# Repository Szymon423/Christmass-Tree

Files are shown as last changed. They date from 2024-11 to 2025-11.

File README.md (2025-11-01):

<div align="center">

# Christmass Tree

</div>

This project is about creating chritmass tree made of PCB with bunch of LEDs. There is not much functionality. I just want it to look pretty.

If You have spare Arduino Uno - You can have Your own little christmass tree.

<p align="center">
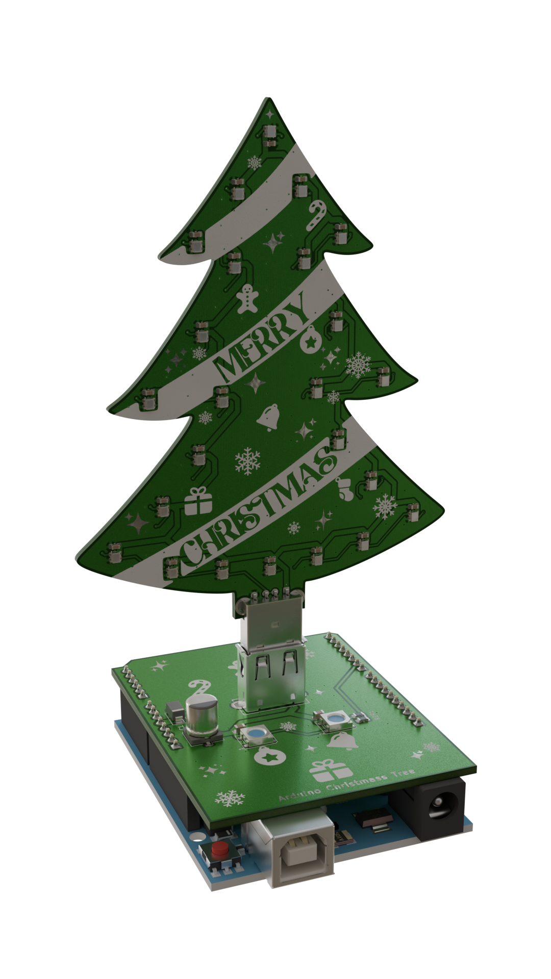
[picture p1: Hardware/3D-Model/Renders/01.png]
opis obrazka
    
</p>

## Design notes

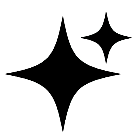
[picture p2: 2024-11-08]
Hardware/KiCad/Assets/star1.png

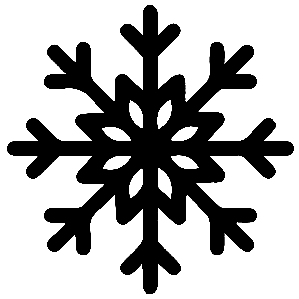
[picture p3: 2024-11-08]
Hardware/KiCad/Assets/snowflake1.png

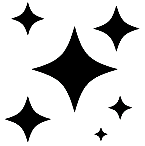
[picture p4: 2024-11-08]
Hardware/KiCad/Assets/star3.png

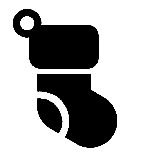
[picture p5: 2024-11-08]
Hardware/KiCad/Assets/sock.png

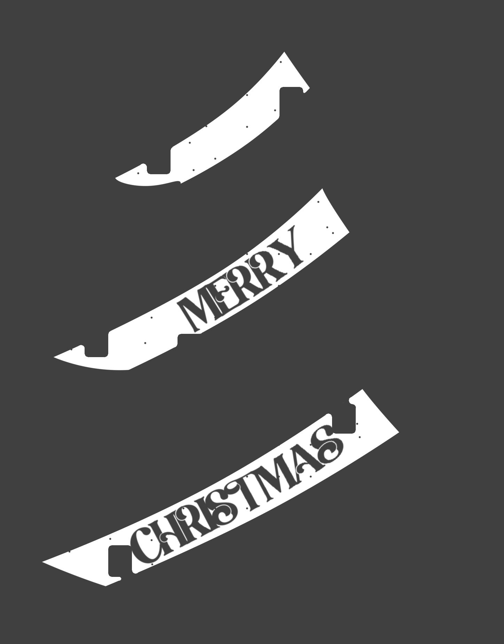
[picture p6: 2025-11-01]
Hardware/KiCad/Assets/Ribbons.png

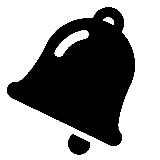
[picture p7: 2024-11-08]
Hardware/KiCad/Assets/bell.png

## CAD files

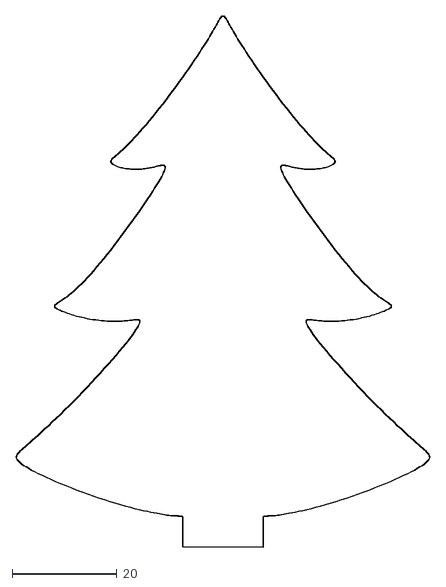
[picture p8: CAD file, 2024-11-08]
Hardware/KiCad/Assets/outline.dxf
78.8 x 101.2

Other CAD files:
Hardware/KiCad/Assets/outline.blend

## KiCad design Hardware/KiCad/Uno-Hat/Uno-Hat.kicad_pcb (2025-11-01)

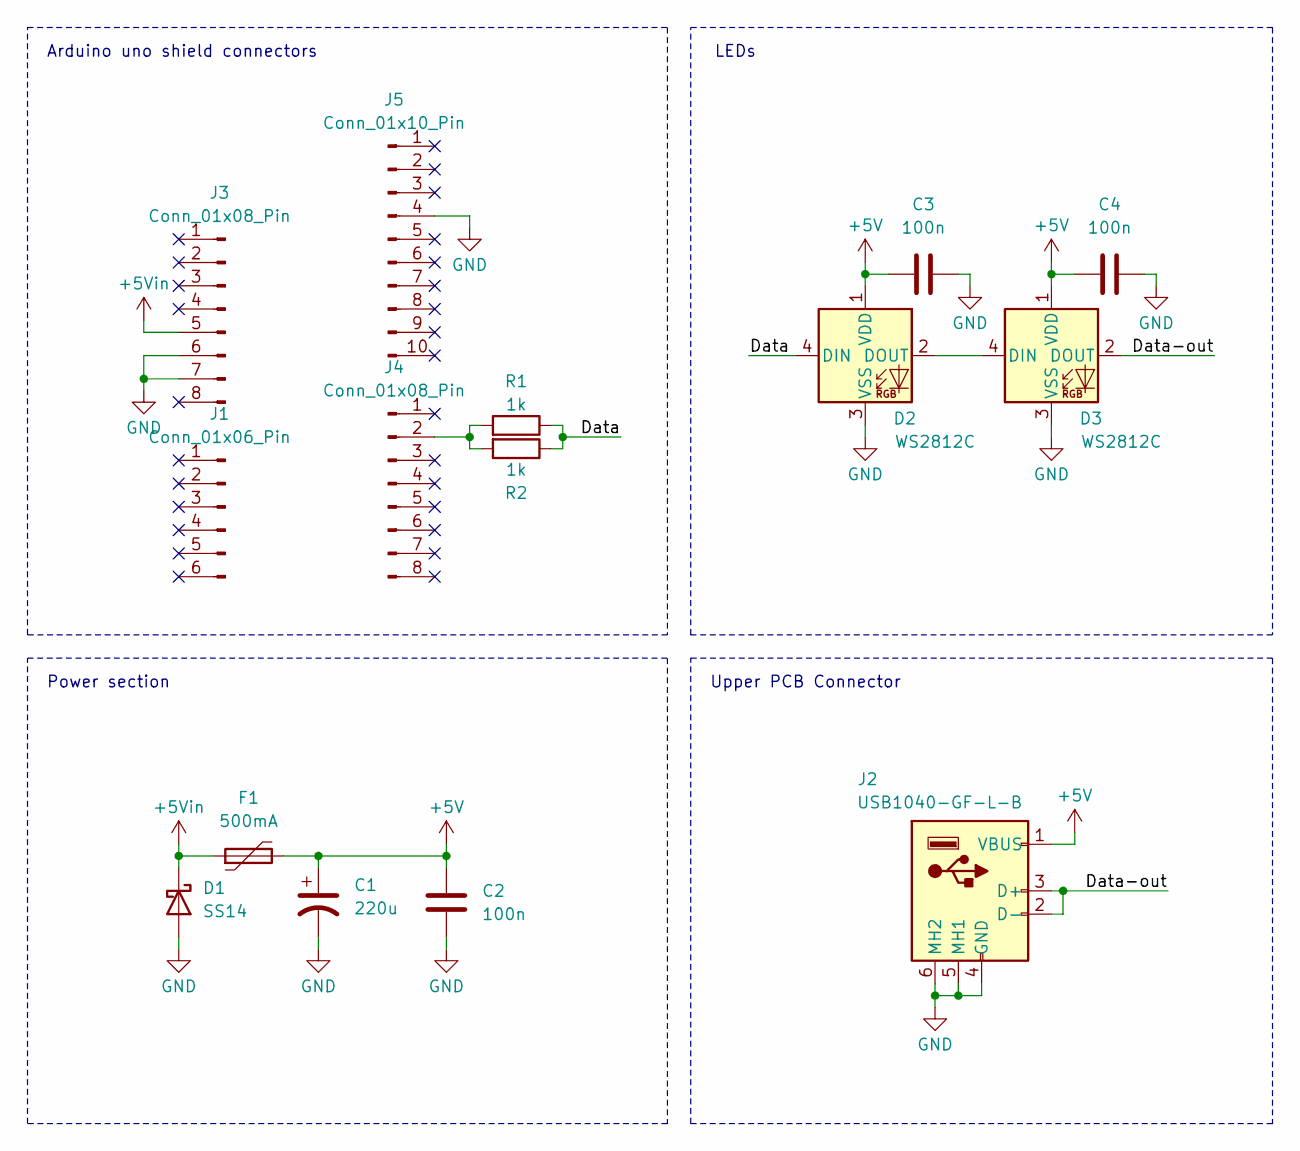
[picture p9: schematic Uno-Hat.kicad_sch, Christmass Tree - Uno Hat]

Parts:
C1: 220u; CP_Elec_6.3x7.7
C2, C3, C4: 100n; C_0805_2012Metric
D1: SS14; D_SMA
D2, D3: WS2812C; LED_WS2812B_PLCC4_5.0x5.0mm_P3.2mm
F1: 500mA; Fuse_1206_3216Metric
J1: Conn_01x06_Pin; PinHeader_1x06_P2.54mm_Vertical
J2: USB1040-GF-L-B; USB1040-GF-L-B-4; Manufacturer_Part_Number USB1040-GF-L-B
J3, J4: Conn_01x08_Pin; PinHeader_1x08_P2.54mm_Vertical
J5: Conn_01x10_Pin; PinHeader_1x10_P2.54mm_Vertical
R1, R2: 1k; R_0805_2012Metric

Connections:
+5V: C1.1, C2.1, C3.1, C4.1, D2.1 (VDD), D3.1 (VDD), F1.2, J2.1 (VBUS)
+5Vin: D1.1 (K), F1.1, J3.5
/Data: D2.4 (DIN), R1.1, R2.1
/Data-out: D3.2 (DOUT), J2.2 (D-), J2.3 (D+)
GND: C1.2, C2.2, C3.2, C4.2, D1.2 (A), D2.3 (VSS), D3.3 (VSS), J2.4 (GND), J2.5 (MH1), J2.6 (MH2), J3.6, J3.7, J5.4
unnamed: D2.2 (DOUT), D3.4 (DIN)
unnamed: J4.2, R1.2, R2.2

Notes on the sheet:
Power section
Arduino uno shield connectors
LEDs
Upper PCB Connector

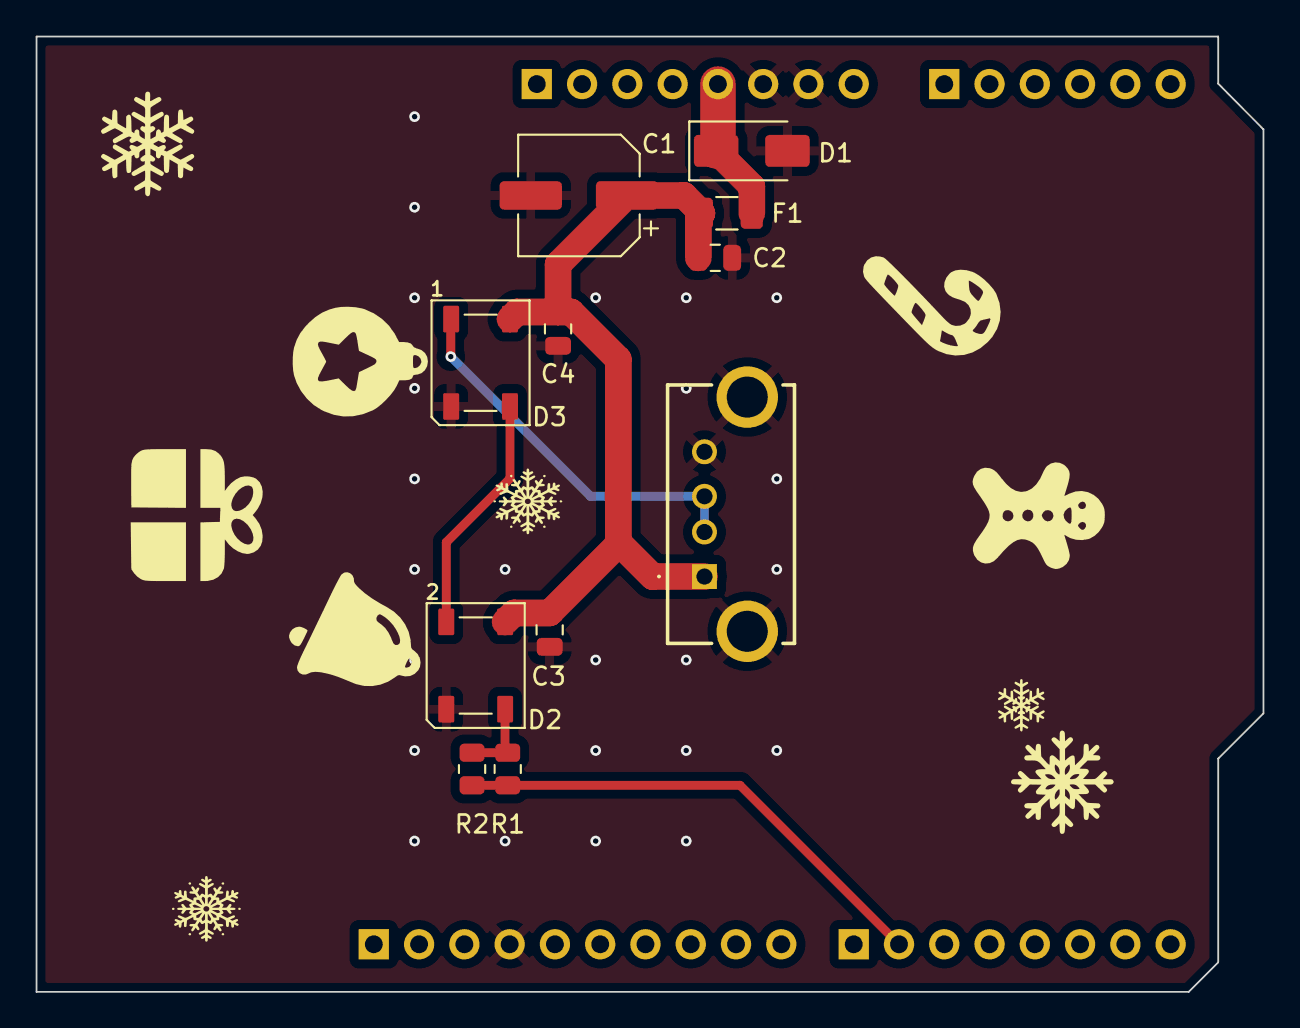
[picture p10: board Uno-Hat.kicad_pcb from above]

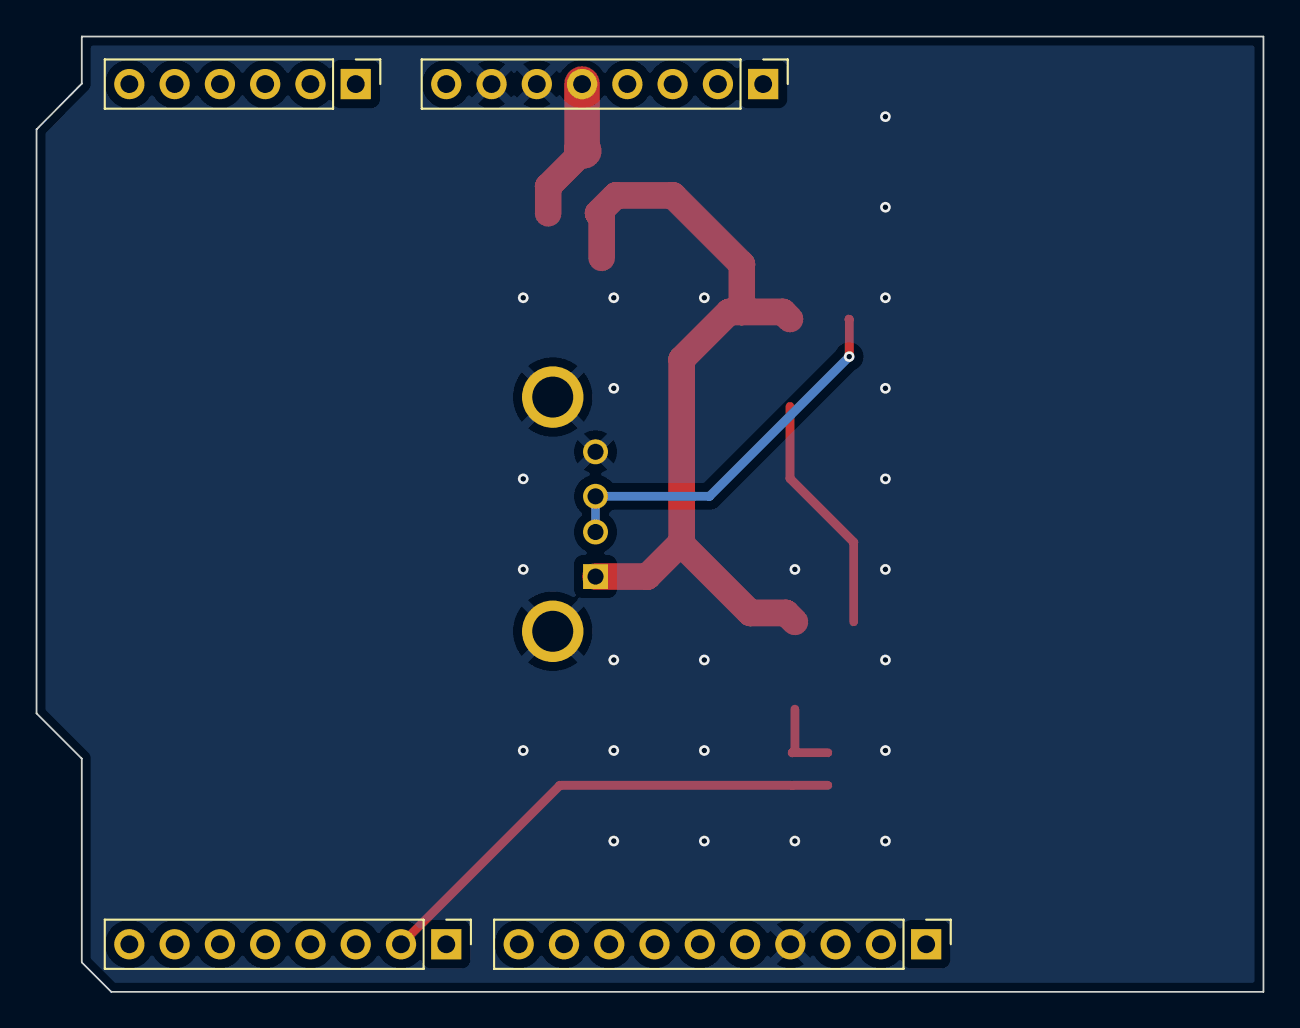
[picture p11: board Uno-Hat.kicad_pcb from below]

Board: 2 copper layers, 68.8 x 53.6 mm, 15 parts (4 on the bottom side), 7 nets.

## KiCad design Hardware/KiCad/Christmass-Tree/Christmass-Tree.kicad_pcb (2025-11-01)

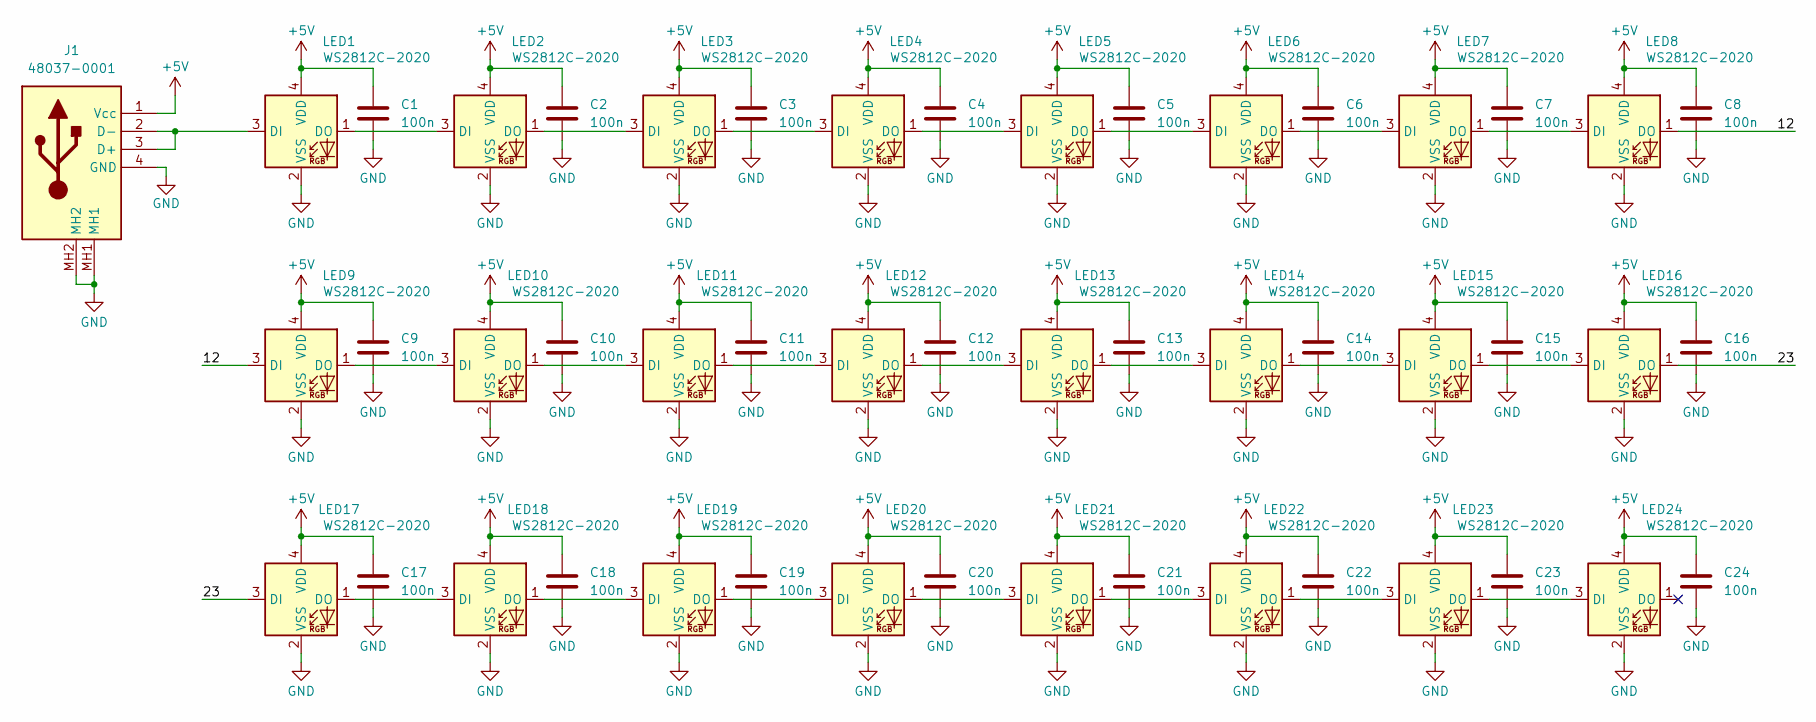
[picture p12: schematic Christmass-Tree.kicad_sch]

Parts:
C1, C2, C3, C4, C5, C6, C7, C8, C9, C10, C11, C12, C13, C14, C15, C16, C17, C18, C19, C20, C21, C22, C23, C24: 100n; C_0603_1608Metric
J1: 48037-0001; 480370001; Manufacturer_Part_Number 48037-0001
LED1, LED2, LED3, LED4, LED5, LED6, LED7, LED8, LED9, LED10, LED11, LED12, LED13, LED14, LED15, LED16, LED17, LED18, LED19, LED20, LED21, LED22, LED23, LED24: WS2812C-2020; WS2812C2020; Manufacturer_Part_Number WS2812C-2020

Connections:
+5V: C1.1, C2.1, C3.1, C4.1, C5.1, C6.1, C7.1, C8.1, C9.1, C10.1, C11.1, C12.1, C13.1, C14.1, C15.1, C16.1, C17.1, C18.1, C19.1, C20.1, C21.1, C22.1, C23.1, C24.1, J1.1 (Vcc), LED1.4 (VDD), LED2.4 (VDD), LED3.4 (VDD), LED4.4 (VDD), LED5.4 (VDD), LED6.4 (VDD), LED7.4 (VDD), LED8.4 (VDD), LED9.4 (VDD), LED10.4 (VDD), LED11.4 (VDD), LED12.4 (VDD), LED13.4 (VDD), LED14.4 (VDD), LED15.4 (VDD), LED16.4 (VDD), LED17.4 (VDD), LED18.4 (VDD), LED19.4 (VDD), LED20.4 (VDD), LED21.4 (VDD), LED22.4 (VDD), LED23.4 (VDD), LED24.4 (VDD)
/12: LED8.1 (DO), LED9.3 (DI)
/23: LED16.1 (DO), LED17.3 (DI)
GND: C1.2, C2.2, C3.2, C4.2, C5.2, C6.2, C7.2, C8.2, C9.2, C10.2, C11.2, C12.2, C13.2, C14.2, C15.2, C16.2, C17.2, C18.2, C19.2, C20.2, C21.2, C22.2, C23.2, C24.2, J1.4 (GND), J1.MH1, J1.MH2, LED1.2 (VSS), LED2.2 (VSS), LED3.2 (VSS), LED4.2 (VSS), LED5.2 (VSS), LED6.2 (VSS), LED7.2 (VSS), LED8.2 (VSS), LED9.2 (VSS), LED10.2 (VSS), LED11.2 (VSS), LED12.2 (VSS), LED13.2 (VSS), LED14.2 (VSS), LED15.2 (VSS), LED16.2 (VSS), LED17.2 (VSS), LED18.2 (VSS), LED19.2 (VSS), LED20.2 (VSS), LED21.2 (VSS), LED22.2 (VSS), LED23.2 (VSS), LED24.2 (VSS)
unnamed: J1.2 (D-), J1.3 (D+), LED1.3 (DI)
unnamed: LED1.1 (DO), LED2.3 (DI)
unnamed: LED2.1 (DO), LED3.3 (DI)
unnamed: LED3.1 (DO), LED4.3 (DI)
unnamed: LED4.1 (DO), LED5.3 (DI)
unnamed: LED5.1 (DO), LED6.3 (DI)
unnamed: LED6.1 (DO), LED7.3 (DI)
unnamed: LED7.1 (DO), LED8.3 (DI)
unnamed: LED9.1 (DO), LED10.3 (DI)
unnamed: LED10.1 (DO), LED11.3 (DI)
unnamed: LED11.1 (DO), LED12.3 (DI)
unnamed: LED12.1 (DO), LED13.3 (DI)
unnamed: LED13.1 (DO), LED14.3 (DI)
unnamed: LED14.1 (DO), LED15.3 (DI)
unnamed: LED15.1 (DO), LED16.3 (DI)
unnamed: LED17.1 (DO), LED18.3 (DI)
unnamed: LED18.1 (DO), LED19.3 (DI)
unnamed: LED19.1 (DO), LED20.3 (DI)
unnamed: LED20.1 (DO), LED21.3 (DI)
unnamed: LED21.1 (DO), LED22.3 (DI)
unnamed: LED22.1 (DO), LED23.3 (DI)
unnamed: LED23.1 (DO), LED24.3 (DI)

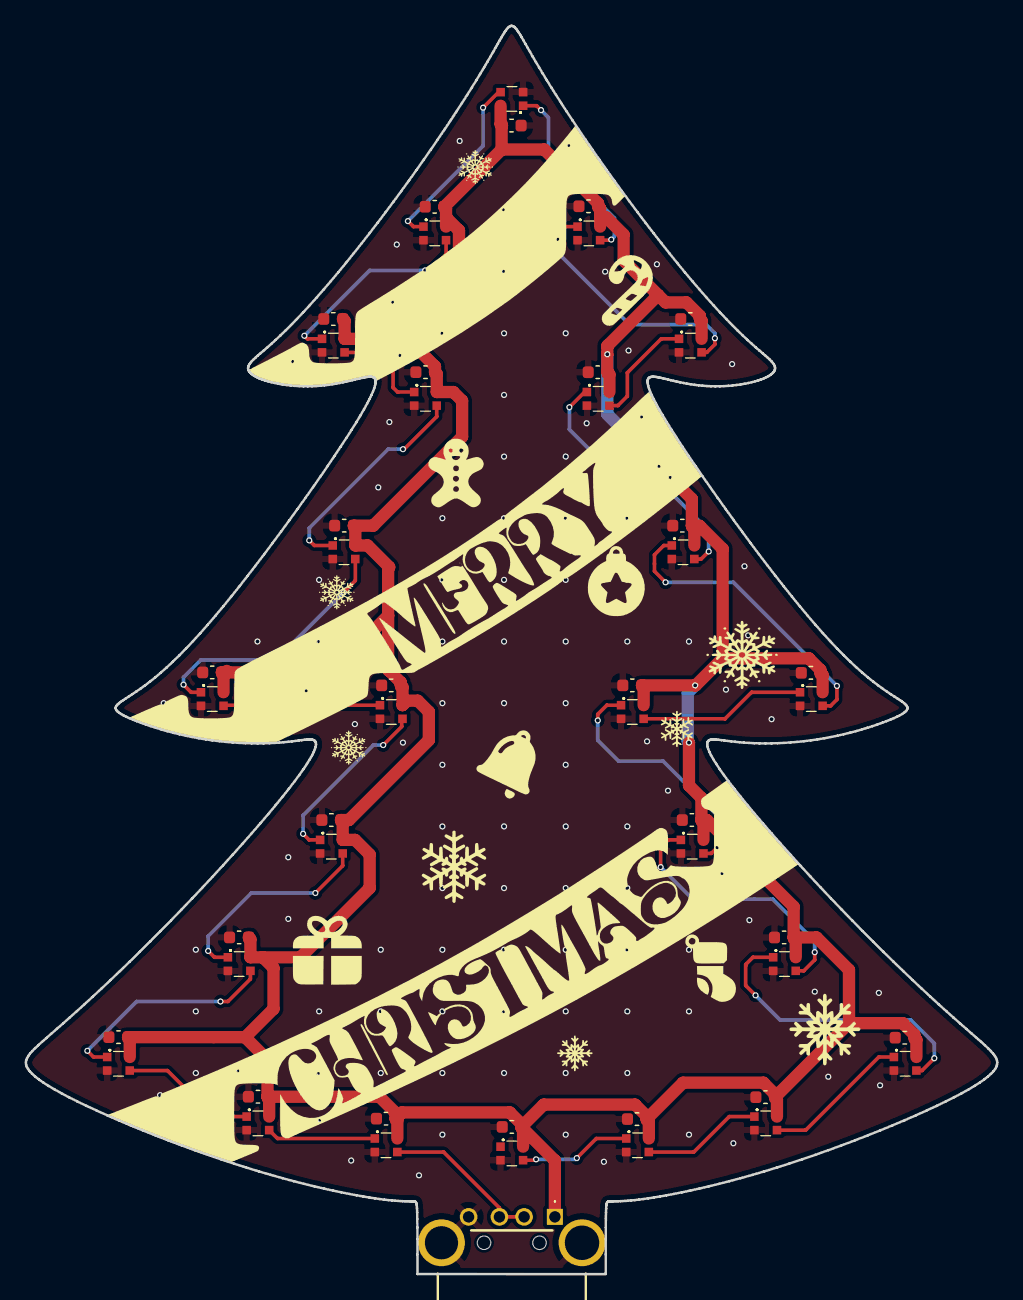
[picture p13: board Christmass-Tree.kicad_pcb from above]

Board: 2 copper layers, 78.8 x 101.2 mm, 49 parts (0 on the bottom side), 26 nets.

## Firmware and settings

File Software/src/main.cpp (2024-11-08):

#include <Adafruit_NeoPixel.h>
#include <Encoder.h>
#include "definitions.hpp"

Adafruit_NeoPixel pixels = Adafruit_NeoPixel(Constants::PixelsNumber, Constants::PixelsPin, NEO_GRB + NEO_KHZ800);
Encoder encoder(Constants::EncoderBPin, Constants::EncoderAPin);

volatile int mode = 0;
int brightness = 80;
long oldPosition = 0;
long firstPixelHue = 0;
float currentPixel = 0.0; // Zmieniono na float
int breathIndex = 0;

void changeMode();
void rainbowCycleStep();
void colorWipeStep(bool colorful);
void randomFlashesStep(bool colorful);
void breathingStep(bool colorful);
void solidColorStep(); // Nowa funkcja

void setup() {
    pinMode(Constants::EncoderButtonPin, INPUT);
    attachInterrupt(digitalPinToInterrupt(Constants::EncoderButtonPin), changeMode, FALLING);
    pixels.begin();
    pixels.show();
}

void loop() {
    long newPosition = encoder.read();
    if (newPosition != oldPosition) {
        oldPosition = newPosition;
        brightness = constrain(map(newPosition, 0, 192, 0, 255), 0, 255); // Zmieniono max pozycje enkodera na 96
    }

    switch (mode) {
        case 0:
            rainbowCycleStep();
            break;
        case 1:
            breathingStep(false);
            break;
        case 2:
            breathingStep(true);
            break;
        case 3:
            colorWipeStep(false);
            break;
        case 4:
            colorWipeStep(true);
            break;
        case 5:
            randomFlashesStep(false);
            break;
        case 6:
            randomFlashesStep(true);
            break;
        case 7:
            solidColorStep(); // Nowy tryb
            break;
        default:
            mode = 0;
            break;
    }
    delay(20);
}

void changeMode() {
    mode = (mode + 1) % 8; // Zmieniono na 8, aby uwzględnić nowy tryb
}

void rainbowCycleStep() {
    for (int i = 0; i < pixels.numPixels(); i++) {
        int pixelHue = firstPixelHue + (i * 65536L / pixels.numPixels());
        pixels.setPixelColor(i, pixels.gamma32(pixels.ColorHSV(pixelHue)));
    }
    pixels.setBrightness(brightness);
    pixels.show();
    firstPixelHue += 256;
    if (firstPixelHue >= 5 * 65536) {
        firstPixelHue = 0;
    }
}

void breathingStep(bool colorful) {
    breathIndex = (breathIndex + 1) % 1024;
    int breathBrightness = (exp(sin(breathIndex / 1024.0 * PI)) - 0.36787944) * 108.0;
    breathBrightness = map(breathBrightness, 0, 108, 0, brightness);

    if (colorful) {
        for (int i = 0; i < pixels.numPixels(); i++) {
            int pixelHue = firstPixelHue + (i * 65536L / pixels.numPixels());
            uint32_t color = pixels.gamma32(pixels.ColorHSV(pixelHue));
            pixels.setPixelColor(i, pixels.Color(
                (color >> 16 & 0xFF) * breathBrightness / 255,
                (color >> 8 & 0xFF) * breathBrightness / 255,
                (color & 0xFF) * breathBrightness / 255
            ));
        }
    } else {
        pixels.fill(pixels.Color(255, 223, 186));
        pixels.setBrightness(breathBrightness);
    }
    pixels.show();

    if (colorful) {
        firstPixelHue += 64;
    }
}

void randomFlashesStep(bool colorful) {
    static int flashBrightness[Constants::PixelsNumber] = {0};
    static int flashDecay[Constants::PixelsNumber] = {0};

    int numFlashes = random(1, 6);
    for (int n = 0; n < numFlashes; n++) {
        int pixel = random(Constants::PixelsNumber);
        if (flashBrightness[pixel] == 0) {
            flashBrightness[pixel] = random(128, 256);
            flashDecay[pixel] = random(1, 5);
        }
    }

    for (int i = 0; i < Constants::PixelsNumber; i++) {
        if (flashBrightness[i] > 0) {
            if (colorful) {
                int pixelHue = firstPixelHue + (i * 65536L / pixels.numPixels());
                uint32_t color = pixels.gamma32(pixels.ColorHSV(pixelHue));
                pixels.setPixelColor(i, pixels.Color(
                    (color >> 16 & 0xFF) * flashBrightness[i] / 255,
                    (color >> 8 & 0xFF) * flashBrightness[i] / 255,
                    (color & 0xFF) * flashBrightness[i] / 255
                ));
            } else {
                pixels.setPixelColor(i, pixels.Color(flashBrightness[i], flashBrightness[i], flashBrightness[i]));
            }
            flashBrightness[i] -= flashDecay[i];
            if (flashBrightness[i] < 0) flashBrightness[i] = 0;
        } else {
            pixels.setPixelColor(i, 0);
        }
    }
    pixels.setBrightness(brightness);
    pixels.show();

    if (colorful) {
        firstPixelHue += 64;
    }
}

void colorWipeStep(bool colorful) {
    const float fadeDistance = 3.0;
    pixels.clear();

    for (int i = 0; i < pixels.numPixels(); i++) {
        float distance = fabs(currentPixel - i);
        if (distance < fadeDistance) {
            float intensity = 1.0 - (distance / fadeDistance);
            int pixelBrightness = intensity * brightness;
            if (colorful) {
                int pixelHue = firstPixelHue + (i * 65536L / pixels.numPixels());
                uint32_t color = pixels.gamma32(pixels.ColorHSV(pixelHue));
                pixels.setPixelColor(i, pixels.Color(
                    (color >> 16 & 0xFF) * pixelBrightness / 255,
                    (color >> 8 & 0xFF) * pixelBrightness / 255,
                    (color & 0xFF) * pixelBrightness / 255
                ));
            } else {
                pixels.setPixelColor(i, pixels.Color(
                    255 * pixelBrightness / 255,
                    223 * pixelBrightness / 255,
                    186 * pixelBrightness / 255
                ));
            }
        }
    }
    pixels.setBrightness(brightness);
    pixels.show();
    currentPixel += 0.1;
    if (currentPixel >= pixels.numPixels()) {
        currentPixel -= pixels.numPixels();
    }

    if (colorful) {
        firstPixelHue += 64;
    }
}

void solidColorStep() {
    int pixelHue = firstPixelHue;
    uint32_t color = pixels.gamma32(pixels.ColorHSV(pixelHue));
    pixels.fill(color);
    pixels.setBrightness(brightness);
    pixels.show();
    firstPixelHue += 64; // Wolniejsza zmiana koloru
    if (firstPixelHue >= 65536) {
        firstPixelHue = 0;
    }
}

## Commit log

2023-12-13 switch on interrupt with mode selector (brightness / delay)
2023-12-14 some random stuff + issue on long press
    [main.cpp]
2023-12-15 linear mode - color change not working corectly
    [main.cpp]
2024-11-08 New version of code just dropped
    [Bottom.blend, Bottom.stl, Gift.blend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]
2025-11-01 Added KiCad Hardware project
    [Bottom.blend, Bottom.stl, Christmass-Tree.kicad_pcb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]
